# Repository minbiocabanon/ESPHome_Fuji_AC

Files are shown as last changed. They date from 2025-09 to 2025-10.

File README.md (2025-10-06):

# ESPHome_Fuji_AC

## Hardware

Totaly inspired by FOSV [Fuji Atom Interface](https://github.com/FOSV/Fuji-Atom-Interface). Great project but I bring these improvements :
- Easier composants to weld (size >= 0603, no QFN nor LGA)
- More 'professional' schematic design : schematic more , and organized, TVS added, decoupling capacitors and datasheet recommandations added.
- More 'professional' layout design : use power plan, 4 layers stackup, and state-of-art routing rules (EMC, DFx rules,...)
- Add minors improvments : 12V/5V leds, testpoints, reverse polarity protection on 12V.

Design tools
- Altium Designer 25.8

### What does it looks like ?

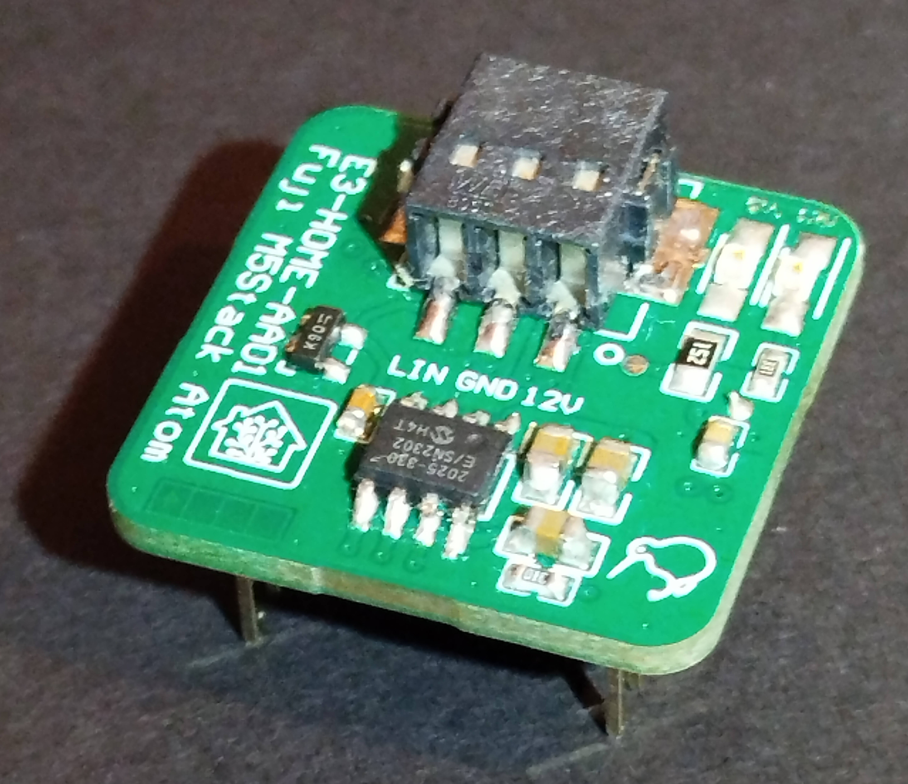
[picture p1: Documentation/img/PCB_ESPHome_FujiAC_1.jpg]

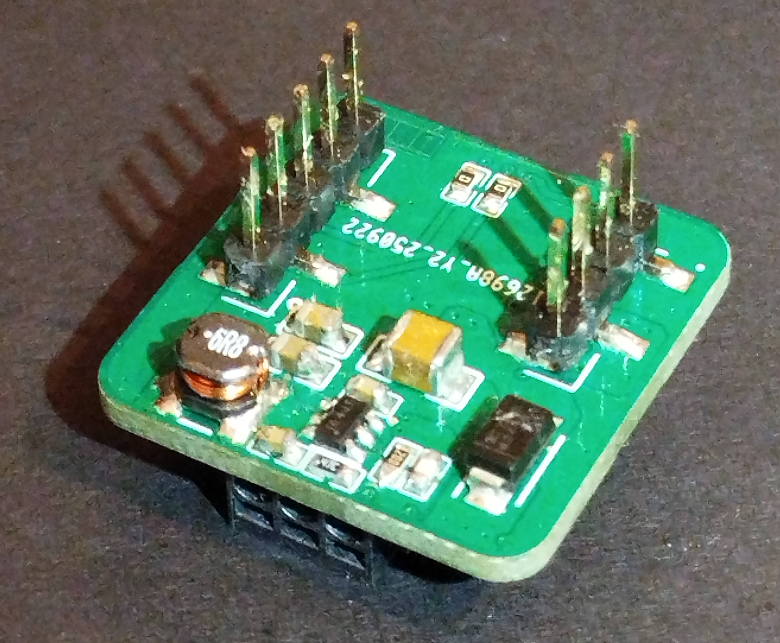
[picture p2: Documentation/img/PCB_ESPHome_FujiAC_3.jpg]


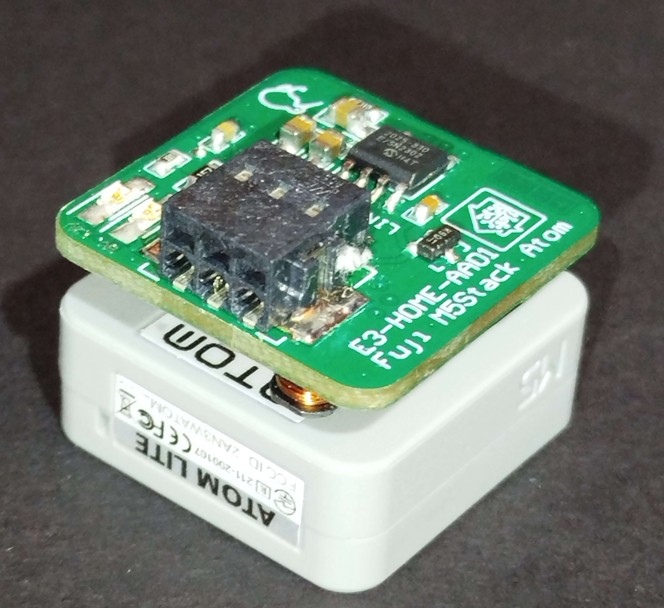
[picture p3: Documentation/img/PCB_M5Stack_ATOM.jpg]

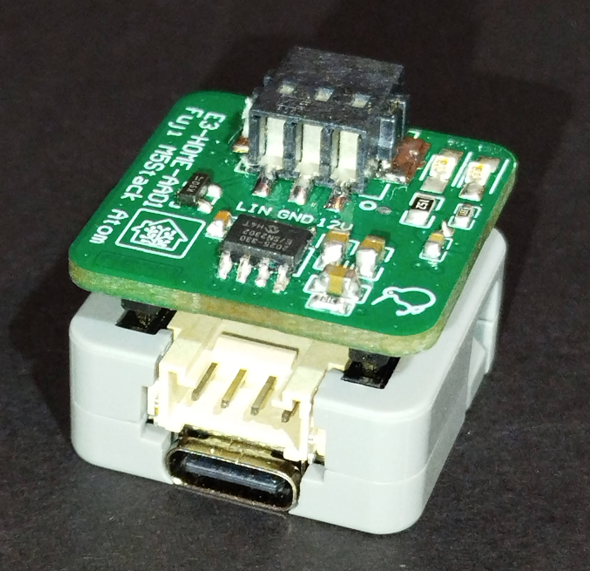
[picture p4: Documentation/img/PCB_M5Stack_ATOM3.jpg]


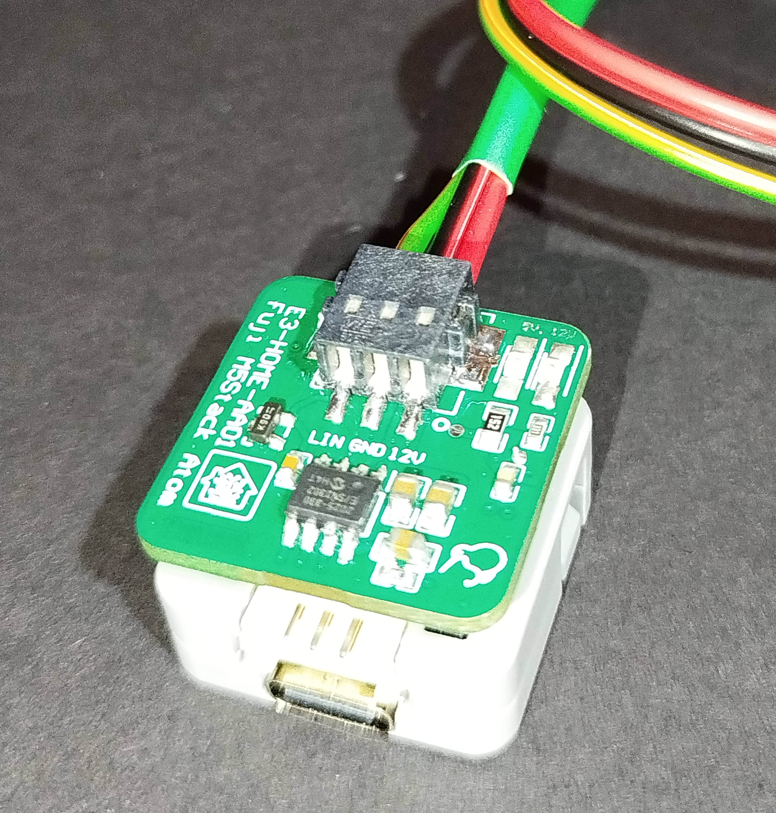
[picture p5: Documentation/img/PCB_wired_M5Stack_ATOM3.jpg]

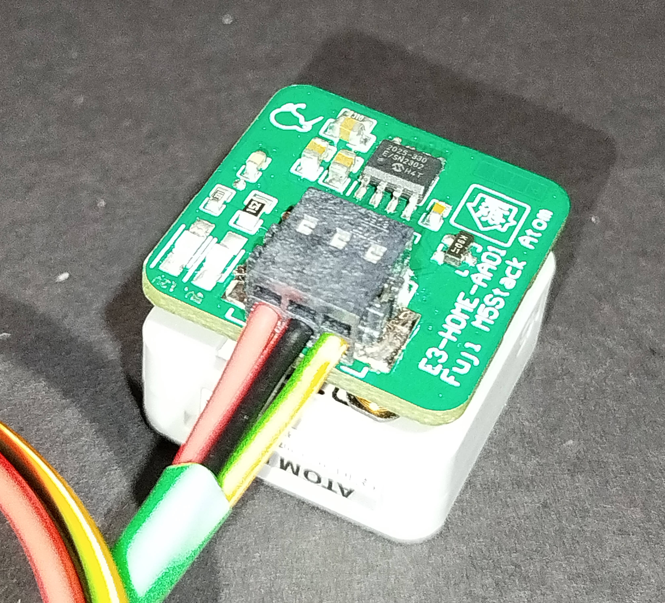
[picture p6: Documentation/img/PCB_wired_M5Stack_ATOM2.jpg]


## Software

This board can run Omniflux repo [esphome-fujitsu-halcyon](https://github.com/Omniflux/esphome-fujitsu-halcyon)

### ESPHome
This project runs under ESPHome 2025.7.
Not tested with newer version.

### YAML

```
substitutions:
  device_name: "fuji-controller"
  friendly_name: Halcyon Controller
  device_description: Atom Lite + FOSV
  esp_board: m5stack-atom

external_components:
  - source: github://Omniflux/esphome-tzsp
  - source: github://Omniflux/esphome-fujitsu-halcyon

packages:
  #wifi: !include common/wifi.yaml

esphome:
  name: ${device_name}
  friendly_name: ${friendly_name}
  comment: ${device_description}

esp32:
  board: ${esp_board}
  framework:
    type: esp-idf

#logger:
#  level: DEBUG

button:
  - platform: restart
    name: Restart
  - platform: safe_mode
    name: Restart (Safe Mode)

sensor:
- platform: uptime
  name: "Uptime"

uart:
  tx_pin: GPIO22  # Device dependent
  rx_pin: GPIO19  # Device dependent
  baud_rate: 500
  parity: EVEN

climate:
- platform: fujitsu-halcyon
  name: None  # Use device friendly_name

  # Fujitsu devices use 0 and 1, but 2-15 should also work. Must not skip addresses
  controller_address: 1  # 0=Primary, 1=Secondary
  #temperature_controller_address: 0  # Fujitsu controller address to read temperature from

  #temperature_sensor_id: my_temperature_sensor  # ESPHome sensor to read temperature from
  #humidity_sensor: my_humidity_sensor  # ESPHome sensor to read humidity from

  #ignore_lock: true  # Ignore child/part/feature lock set on unit or primary/central remote control

  # To capture communications for debugging / analysis
  # Use Wireshark with https://github.com/Omniflux/fujitsu-airstage-h-dissector
  #tzsp:
  #  ip: 192.168.1.20
  #  protocol: 255

# Enable logging
logger:

# Enable Home Assistant API
api:
  encryption:
    key: "xxx"

ota:
  - platform: esphome
    password: "xxx"

wifi:
  ssid: !secret wifi_ssid
  password: !secret wifi_password

  # Enable fallback hotspot (captive portal) in case wifi connection fails
  ap:
    ssid: "Test-Halcyon Fallback Hotspot"
    password: "xxx"

captive_portal:
```

### Screenshot of interface 
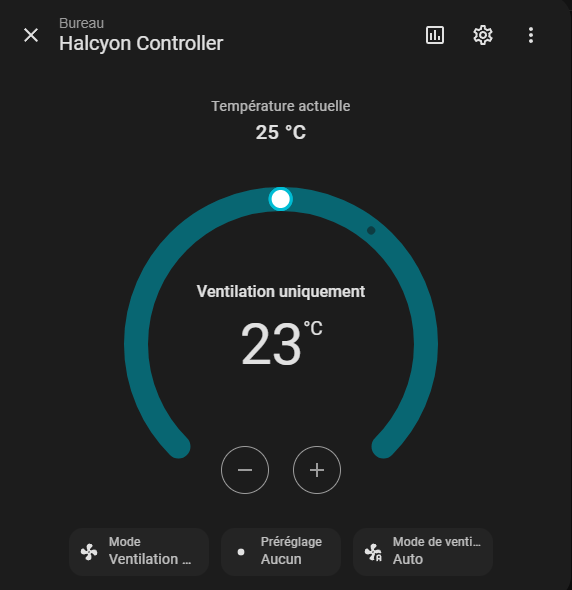
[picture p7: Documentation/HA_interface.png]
Screenshot of interface


## Related projects
- FOSV's [Fuji-Atom-Interface](https://github.com/FOSV/Fuji-Atom-Interface)
- Omniflux repo [esphome-fujitsu-halcyon](https://github.com/Omniflux/esphome-fujitsu-halcyon)
<!-- -->
- Aaron Zhang's [esphome-fujitsu](https://github.com/FujiHeatPump/esphome-fujitsu)
- Jaroslaw Przybylowicz's [fuji-iot](https://github.com/jaroslawprzybylowicz/fuji-iot)
- Raal Goff's [FujiHeatPump](https://github.com/unreality/FujiHeatPump)
- Raal Goff's [FujiHK](https://github.com/unreality/FujiHK)
<!-- -->
- Myles Eftos's [Reverse engineering](https://hackaday.io/project/19473-reverse-engineering-a-fujitsu-air-conditioner-unit)

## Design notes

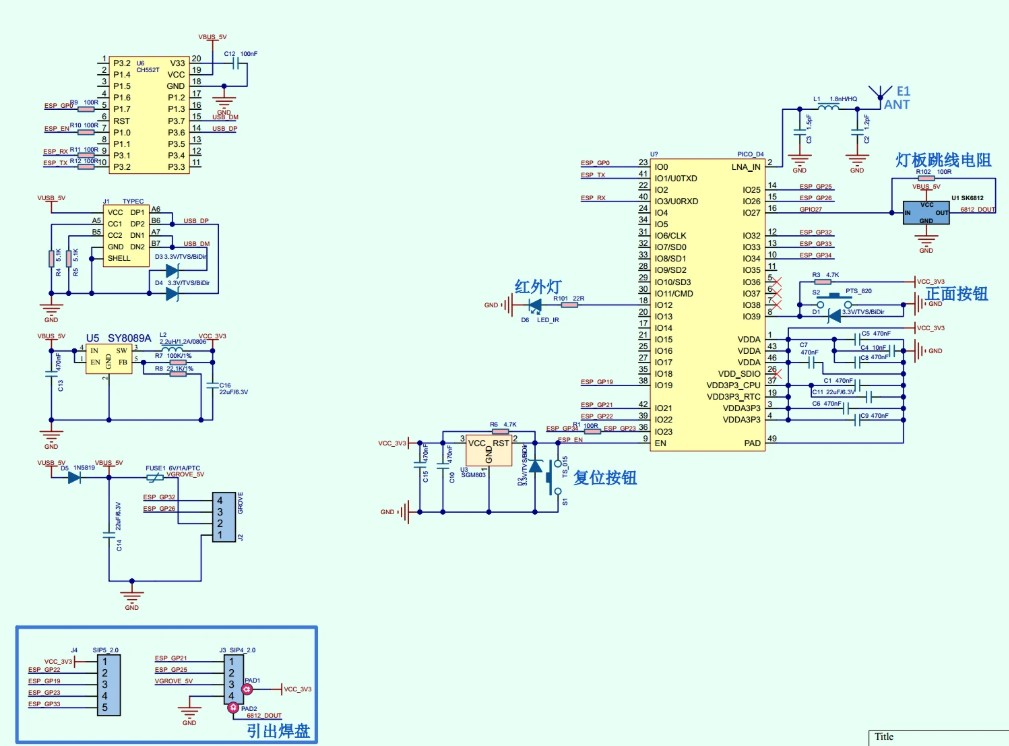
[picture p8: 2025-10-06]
Documentation/Atom_LITE_schematic.jpg

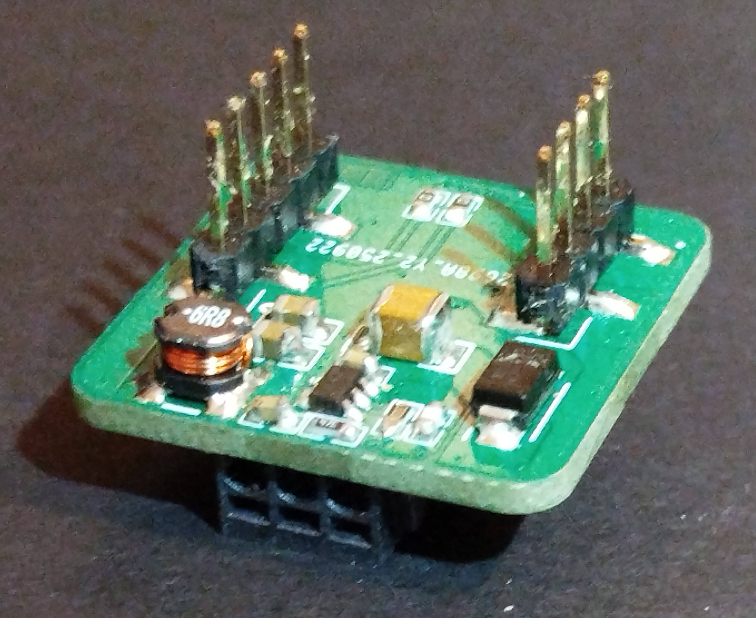
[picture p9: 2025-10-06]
Documentation/img/PCB_ESPHome_FujiAC_2.jpg

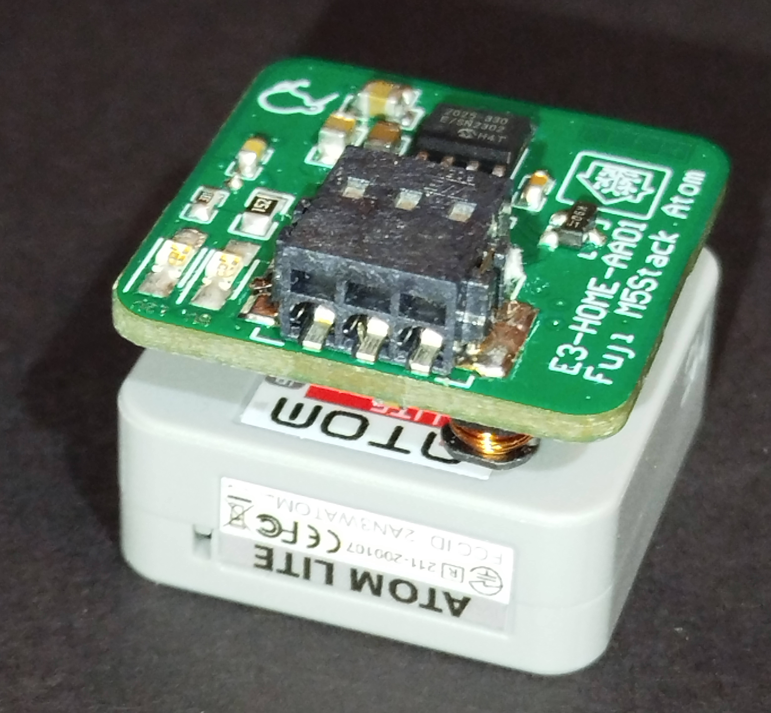
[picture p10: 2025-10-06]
Documentation/img/PCB_M5Stack_ATOM2.jpg

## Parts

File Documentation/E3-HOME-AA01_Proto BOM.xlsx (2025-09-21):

Designator | Comment | Manufacturer Part Number | Manufacturer | Description | Pins | Mounting Type | Layer | Quantity | Commande
J100 | 691805010303 | 691805010303 | Wurth Elektronik | WR-TBL Series 8050 - 3 pins 2.50 mm Screwless SMT | 8 | CMS | Bottom | 1 | Samples demandés à WE
U100 | AP63300WU-7 | AP63300WU-7 | Diodes Incorporated | Régulateurs de tension de commutation DCDC Conv HV Buck TSOT26 T&R 3K | 6 | CMS | Top | 1 | OI
D102, D103 | APT3216LZGCK | APT3216LZGCK | Kingbright | LED CMS Green 3.2x1.6mm | 2 | CMS | Bottom | 2 | Samples demandés à WE
D100 | B340A-13-F | B340A-13-F | Diodes | Diodes et redresseurs Schottky 40V 3A | 2 | CMS | Top | 1 | OI
C101 | 10uF | CAPA_CMS_10uF_50V_1206_10%_X7R |  | 10uF_50V_1206_10%_X7R | 2 | CMS | Top | 1 | OI
C104, C105, C106, C107, C108 | 22uF | CAPA_CMS_22uF_16V_0805_10%_X5R |  | 22uF_16V_0805_10%_X5R | 2 | CMS | Top, Bottom | 5 | OI
C103 | 47pF | CAPA_CMS_47pF_50V_0603_5%_X7R |  | 47pF_50V_0603_5%_X7R | 2 | CMS | Top | 1 | OI
C100, C102, C109 | 100nF | CAPA_CMS_100nF_50V_0603_5%_X7R |  | 100nF_50V_0603_5%_X7R | 2 | CMS | Top, Bottom | 3 | OI
C110 | 220pF | CAPA_CMS_220pF_50V_0603_10%_X7R |  | 220pF_50V_0603_10%_X7R | 2 | CMS | Bottom | 1 | OI
PCB1 | E7-HOME-AA01 | E7-HOME-AA01 |  | PCB reference | 0 | NONE | None | 1
~~Stencil1~~ | ~~E9-HOME-AA01~~ | ~~E9-HOME-AA01~~ |  | ~~PCB stencil~~ | ~~0~~ | ~~NONE~~ | ~~None~~ | ~~1~~
U101 | MCP2025-330E-SN | MCP2025-330E/SN | Microchip | LIN Transceiver with Voltage Regulator SOIC 3.3V | 8 | CMS | Bottom | 1
D101 | MMBZ27VAL-7-F | MMBZ27VAL-7-F |  | Suppresseurs ESD / diodes TVS 27V 225mW | 3 | CMS | Bottom | 1 | OI
R104, R106 | 0 | RES_CMS_0_1/10W_0603_1% |  | 0_1/10W_0603_1% | 2 | CMS | Top | 2 | OI
R100 | 1K5 | RES_CMS_1K5_1/8W_0805_0.1% |  | 1K5_1/8W_0805_0.1% | 2 | CMS | Bottom | 1 | OI
R103, R105 | 30K1 | RES_CMS_30K1_1/10W_0603_1% |  | 30K1_1/10W_0603_1% | 2 | CMS | Top, Bottom | 2 | OI
R102 | 158K | RES_CMS_158K_1/16W_0603_1% |  | 158K_1/16W_0603_1% | 2 | CMS | Top | 1 | OI
R101 | 330 | RES_CMS_330_1/10W_0603_5% |  | 330_1/10W_0603_5% | 2 | CMS | Bottom | 1 | OI
L100 | SRN5040TA-6R8M | SRN5040TA-6R8M | Bourns | Inductance fixes 6.8uH 2.5A | 2 | CMS | Top | 1 | Samples demandés à WE
J101 | TSM-104-01-L-SV-P-TR | TSM-104-01-L-SV-P-TR | Samtec | Header male SMD 1x4 | 4 | CMS | Top | 1 | Samples demandés à WE
J102 | TSM-105-01-F-SV | TSM-105-01-F-SV | SAMTEC | Header male SMD 1x5 | 5 | CMS | Top | 1 | Samples demandés à WE

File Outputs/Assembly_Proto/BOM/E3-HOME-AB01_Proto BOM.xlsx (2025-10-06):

Manufacturer Part Number | Manufacturer | Comment | Description | Designator | Pins | Mounting Type | Layer | Quantity
691805010303 | Wurth Elektronik | 691805010303 | WR-TBL Series 8050 - 3 pins 2.50 mm Screwless SMT | J100 | 8 | CMS | Bottom | 1
AP63300WU-7 | Diodes Incorporated | AP63300WU-7 | Régulateurs de tension de commutation DCDC Conv HV Buck TSOT26 T&R 3K | U100 | 6 | CMS | Top | 1
APT3216LZGCK | Kingbright | APT3216LZGCK | LED CMS Green 3.2x1.6mm | D102, D103 | 2 | CMS | Bottom | 2
B340A-13-F | Diodes | B340A-13-F | Diodes et redresseurs Schottky 40V 3A | D100 | 2 | CMS | Top | 1
CAPA_CMS_10uF_50V_1206_10%_X7R |  | 10uF | 10uF_50V_1206_10%_X7R | C101 | 2 | CMS | Top | 1
CAPA_CMS_22uF_16V_0805_10%_X5R |  | 22uF | 22uF_16V_0805_10%_X5R | C104, C105, C106, C107, C108 | 2 | CMS | Top, Bottom | 5
CAPA_CMS_47pF_50V_0603_5%_X7R |  | 47pF | 47pF_50V_0603_5%_X7R | C103 | 2 | CMS | Top | 1
CAPA_CMS_100nF_50V_0603_5%_X7R |  | 100nF | 100nF_50V_0603_5%_X7R | C100, C102, C109 | 2 | CMS | Top, Bottom | 3
CAPA_CMS_220pF_50V_0603_10%_X7R |  | 220pF | 220pF_50V_0603_10%_X7R | C110 | 2 | CMS | Bottom | 1
E7-HOME-AB01 |  | E7-HOME-AB01 | PCB reference | PCB1 | 0 | NONE | None | 1
E9-HOME-AB01 |  | E9-HOME-AB01 | PCB stencil | Stencil1 | 0 | NONE | None | 1
MCP2025-330E/SN | Microchip | MCP2025-330E-SN | LIN Transceiver with Voltage Regulator SOIC 3.3V | U101 | 8 | CMS | Bottom | 1
MMBZ27VAL-7-F |  | MMBZ27VAL-7-F | Suppresseurs ESD / diodes TVS 27V 225mW | D101 | 3 | CMS | Bottom | 1
RES_CMS_0_1/10W_0603_1% |  | 0 | 0_1/10W_0603_1% | R104, R106 | 2 | CMS | Top | 2
RES_CMS_1K_1/10W_0603_1% |  | 1K | 1K_1/10W_0603_1% | R101 | 2 | CMS | Bottom | 1
RES_CMS_3K_1/8W_0805_1% |  | 3K | 3K_1/8W_0805_1% | R100 | 2 | CMS | Bottom | 1
RES_CMS_30K1_1/10W_0603_1% |  | 30K1 | 30K1_1/10W_0603_1% | R103, R105 | 2 | CMS | Top, Bottom | 2
RES_CMS_158K_1/16W_0603_1% |  | 158K | 158K_1/16W_0603_1% | R102 | 2 | CMS | Top | 1
SRN5040TA-6R8M | Bourns | SRN5040TA-6R8M | Inductance fixes 6.8uH 2.5A | L100 | 2 | CMS | Top | 1
TSM-104-01-L-SV-P-TR | Samtec | TSM-104-01-L-SV-P-TR | Header male SMD 1x4 | J101 | 4 | CMS | Top | 1
TSM-105-01-F-SV | SAMTEC | TSM-105-01-F-SV | Header male SMD 1x5 | J102 | 5 | CMS | Top | 1

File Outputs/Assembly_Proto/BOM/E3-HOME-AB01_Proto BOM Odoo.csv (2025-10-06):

Manufacturer Part Number | Quantity | Layer
691805010303 | 1 | Bottom
AP63300WU-7 | 1 | Top
APT3216LZGCK | 2 | Bottom
B340A-13-F | 1 | Top
CAPA_CMS_10uF_50V_1206_10%_X7R | 1 | Top
CAPA_CMS_22uF_16V_0805_10%_X5R | 5 | Top, Bottom
CAPA_CMS_47pF_50V_0603_5%_X7R | 1 | Top
CAPA_CMS_100nF_50V_0603_5%_X7R | 3 | Top, Bottom
CAPA_CMS_220pF_50V_0603_10%_X7R | 1 | Bottom
E7-HOME-AB01 | 1 | None
E9-HOME-AB01 | 1 | None
MCP2025-330E/SN | 1 | Bottom
MMBZ27VAL-7-F | 1 | Bottom
RES_CMS_0_1/10W_0603_1% | 2 | Top
RES_CMS_1K_1/10W_0603_1% | 1 | Bottom
RES_CMS_3K_1/8W_0805_1% | 1 | Bottom
RES_CMS_30K1_1/10W_0603_1% | 2 | Top, Bottom
RES_CMS_158K_1/16W_0603_1% | 1 | Top
SRN5040TA-6R8M | 1 | Top
TSM-104-01-L-SV-P-TR | 1 | Top
TSM-105-01-F-SV | 1 | Top

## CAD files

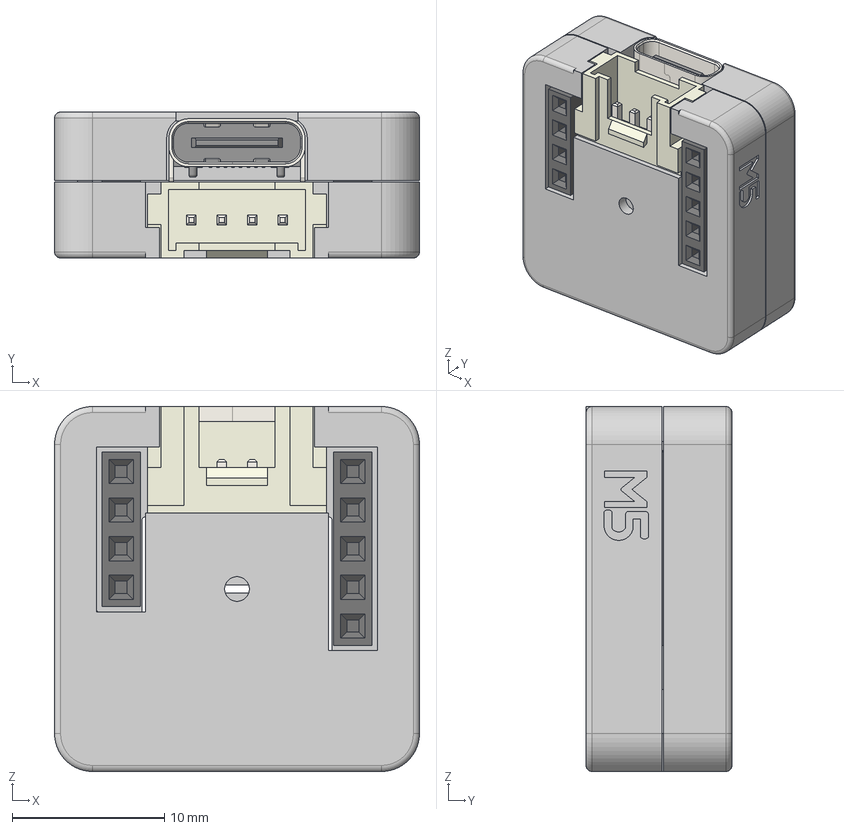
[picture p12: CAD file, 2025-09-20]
Documentation/M5 ATOM Lite.step
24.0 x 9.60 x 24.0 mm
Grove socket
pinsocket_5 v2
pinsocket_4 v3
ConPins
PcbPins
Mold
Frame

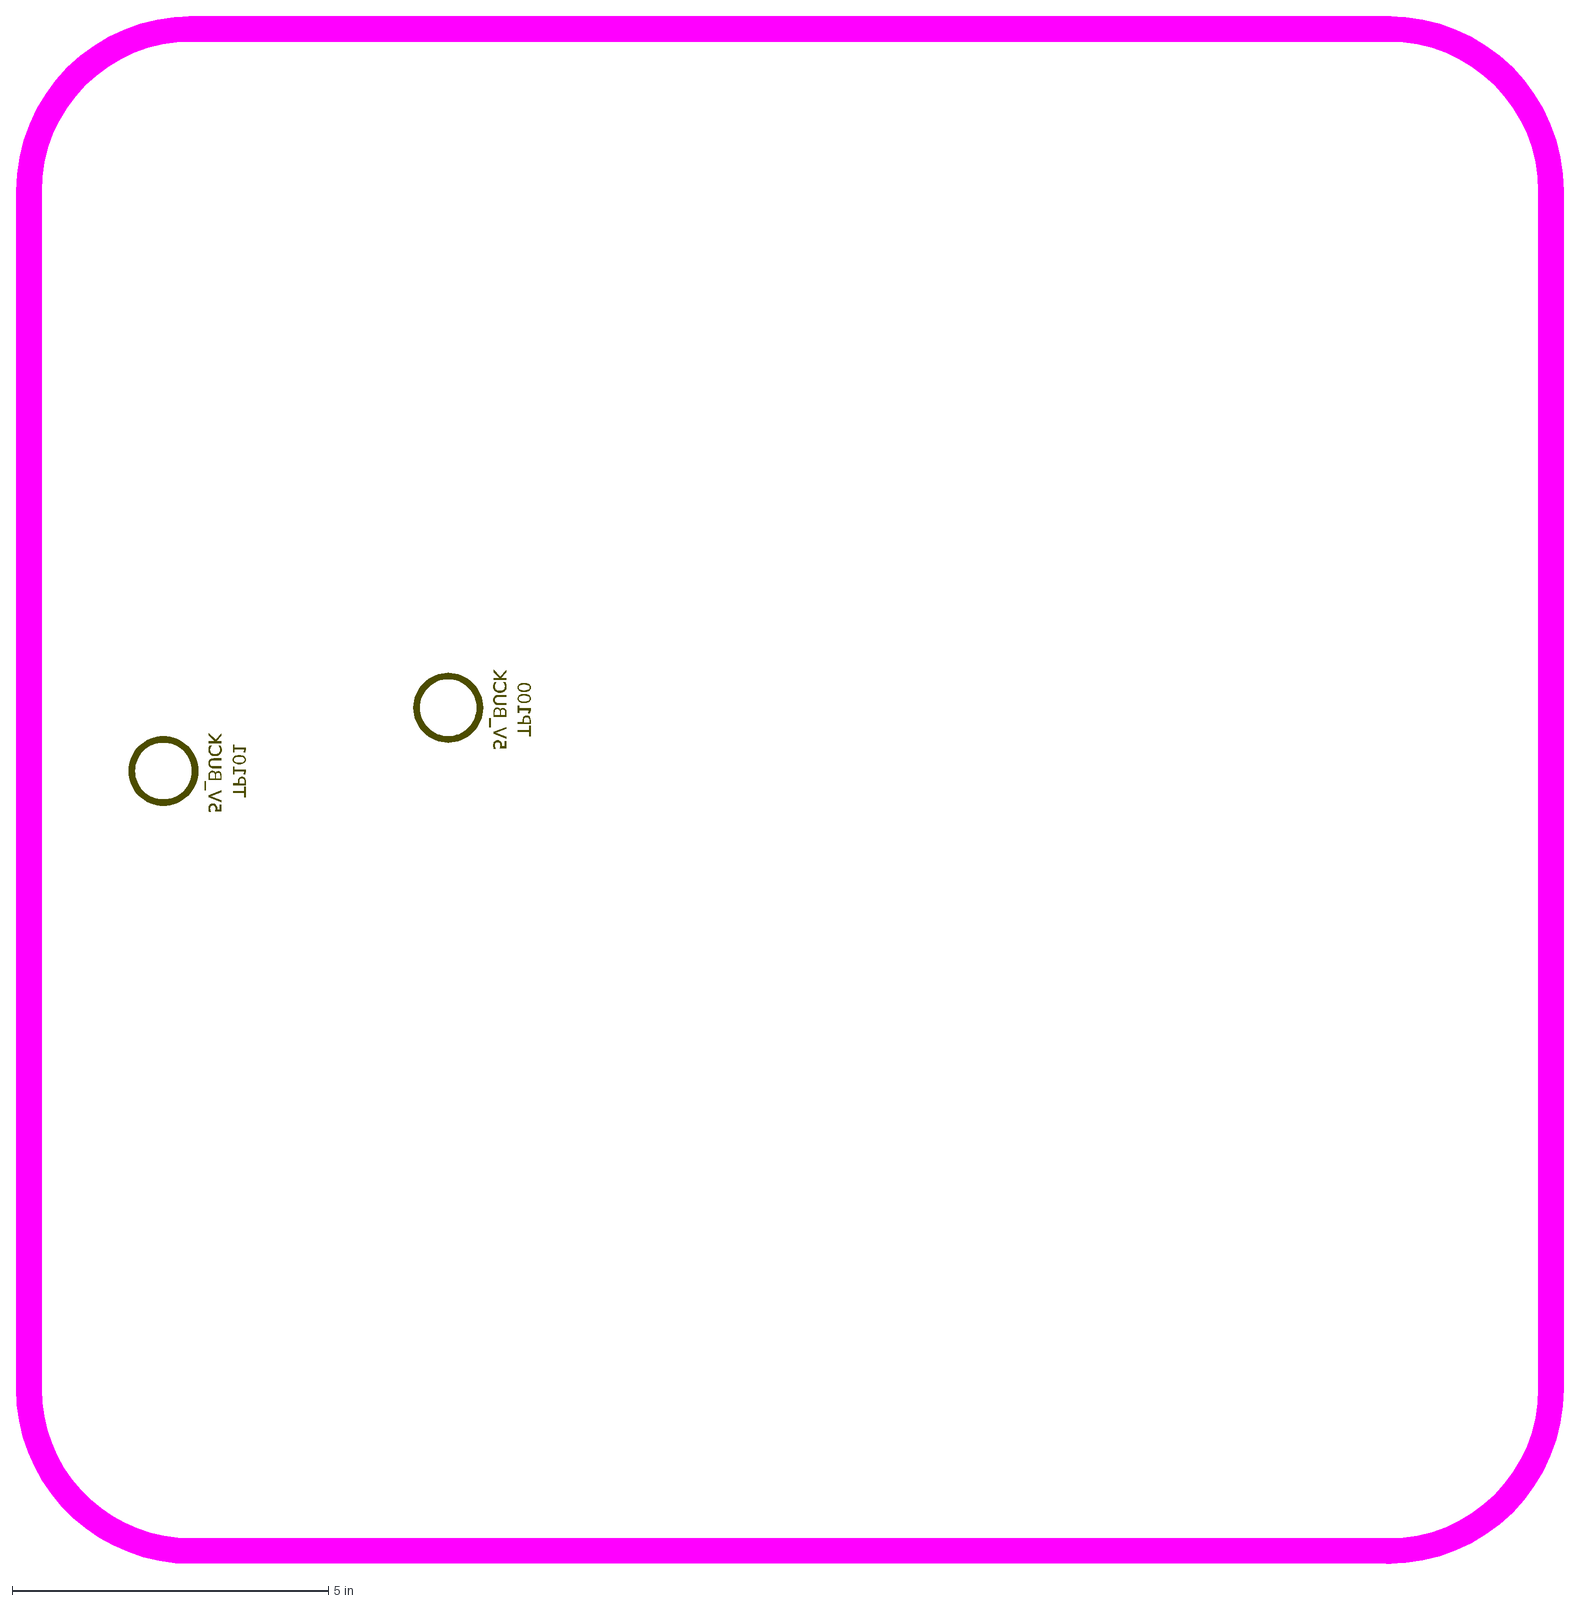
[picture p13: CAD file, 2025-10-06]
Outputs/Mechanical_Proto/E3-HOME-AB01_Proto DXF.DXF
5V_BUCK
TP101
TP100

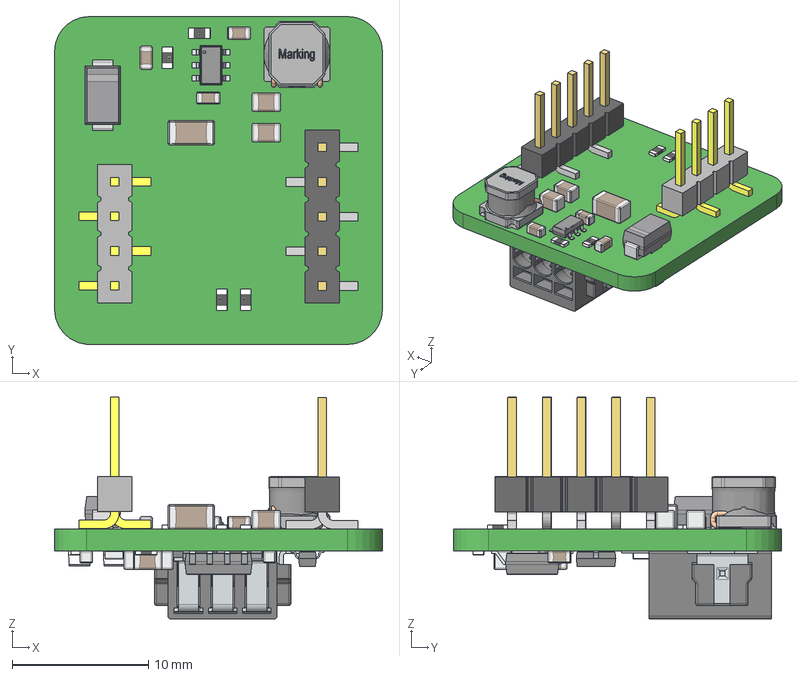
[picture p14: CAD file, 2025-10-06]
Outputs/Mechanical_Proto/E3-HOME-AB01_Proto STEP.step
24.0 x 24.0 x 16.3 mm
TSM-105-01-SV_body
T-1S6-16-F(-01-5-SV)
T-1S6-16-F(-01-5-SV)2
MMBZ27VAL-7-F
PinsArrayLR x 2
SW3dPS-0603 SMD Resistor x 6
T-1S6-16(-01-4-SV)
TSM-104-01-SV_body
6918050103xx_Solder tab x 2
6918050103xx_Pin2 x 3
6918050103xx_Pin1 x 3
User Library-5977703607F x 2
User Library-DO-214AC SMA

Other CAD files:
Outputs/Mechanical_Proto/E3-HOME-AB01_Proto PARASOLID.x_t

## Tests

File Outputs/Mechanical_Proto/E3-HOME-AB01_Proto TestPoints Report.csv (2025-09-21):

Net | Name | X Coord | Y Coord | Side | Hole Size | Type
5V | TP101-1 | 2.1mm | 12.3mm | Bottom | 0mm | Surface mount
12V_FP | TP100-1 | 6.6mm | 13.3mm | Bottom | 0mm | Surface mount

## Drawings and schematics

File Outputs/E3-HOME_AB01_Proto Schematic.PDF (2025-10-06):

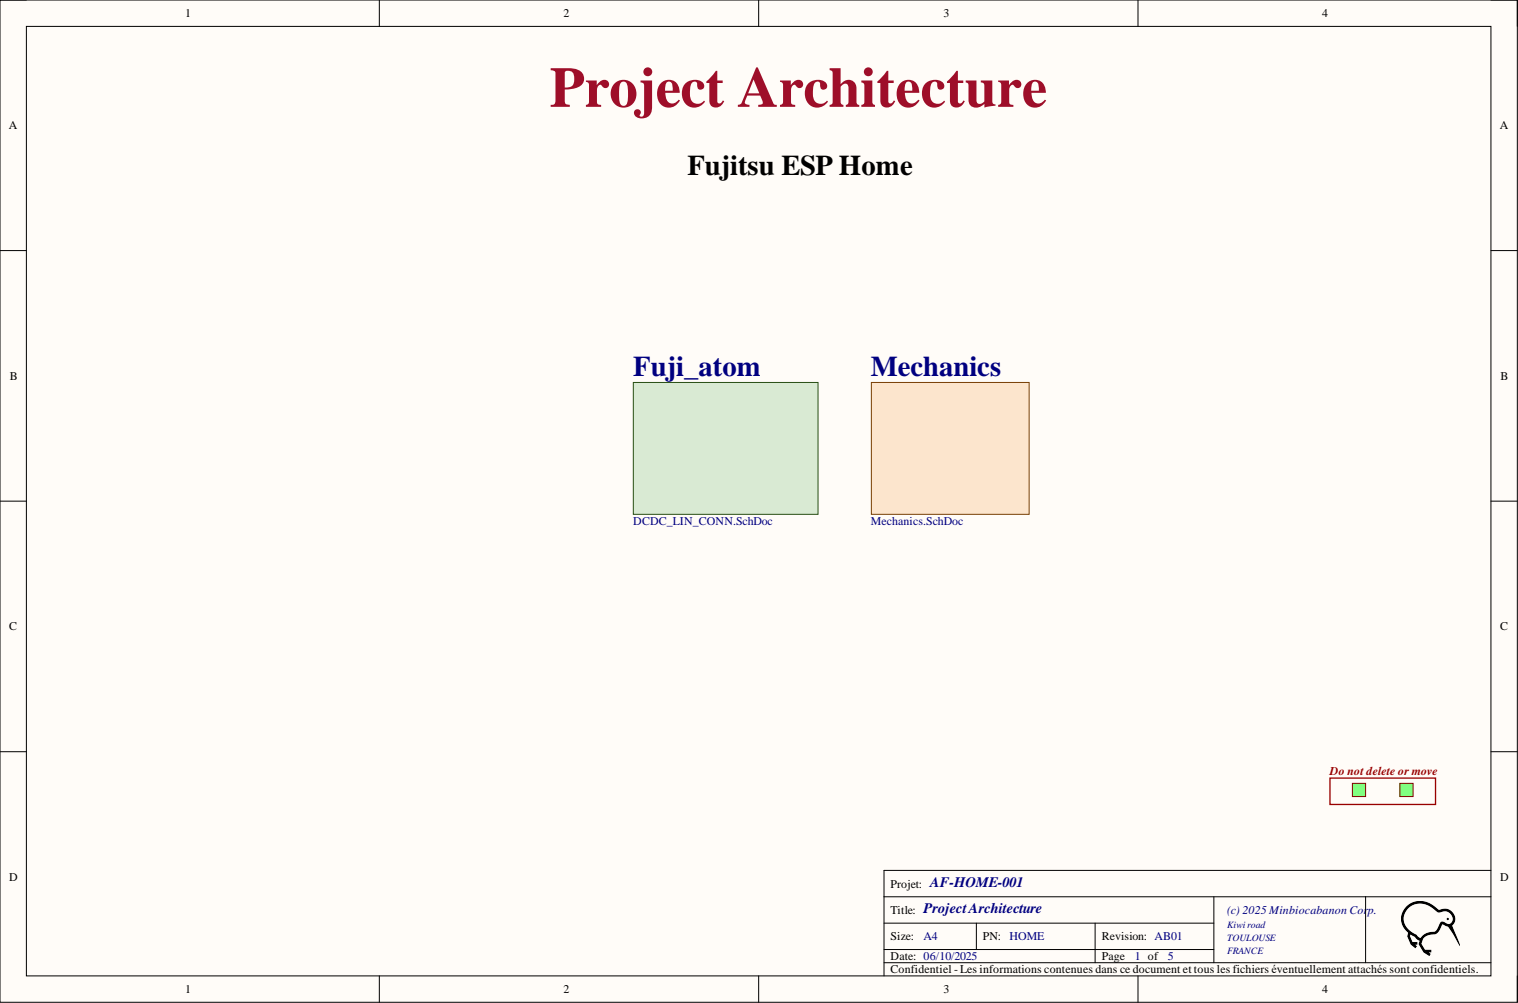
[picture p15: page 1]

Do not delete or move

Date:
Confidentiel - Les informations contenues dans ce document et tous les fichiers éventuellement attachés sont confidentiels.

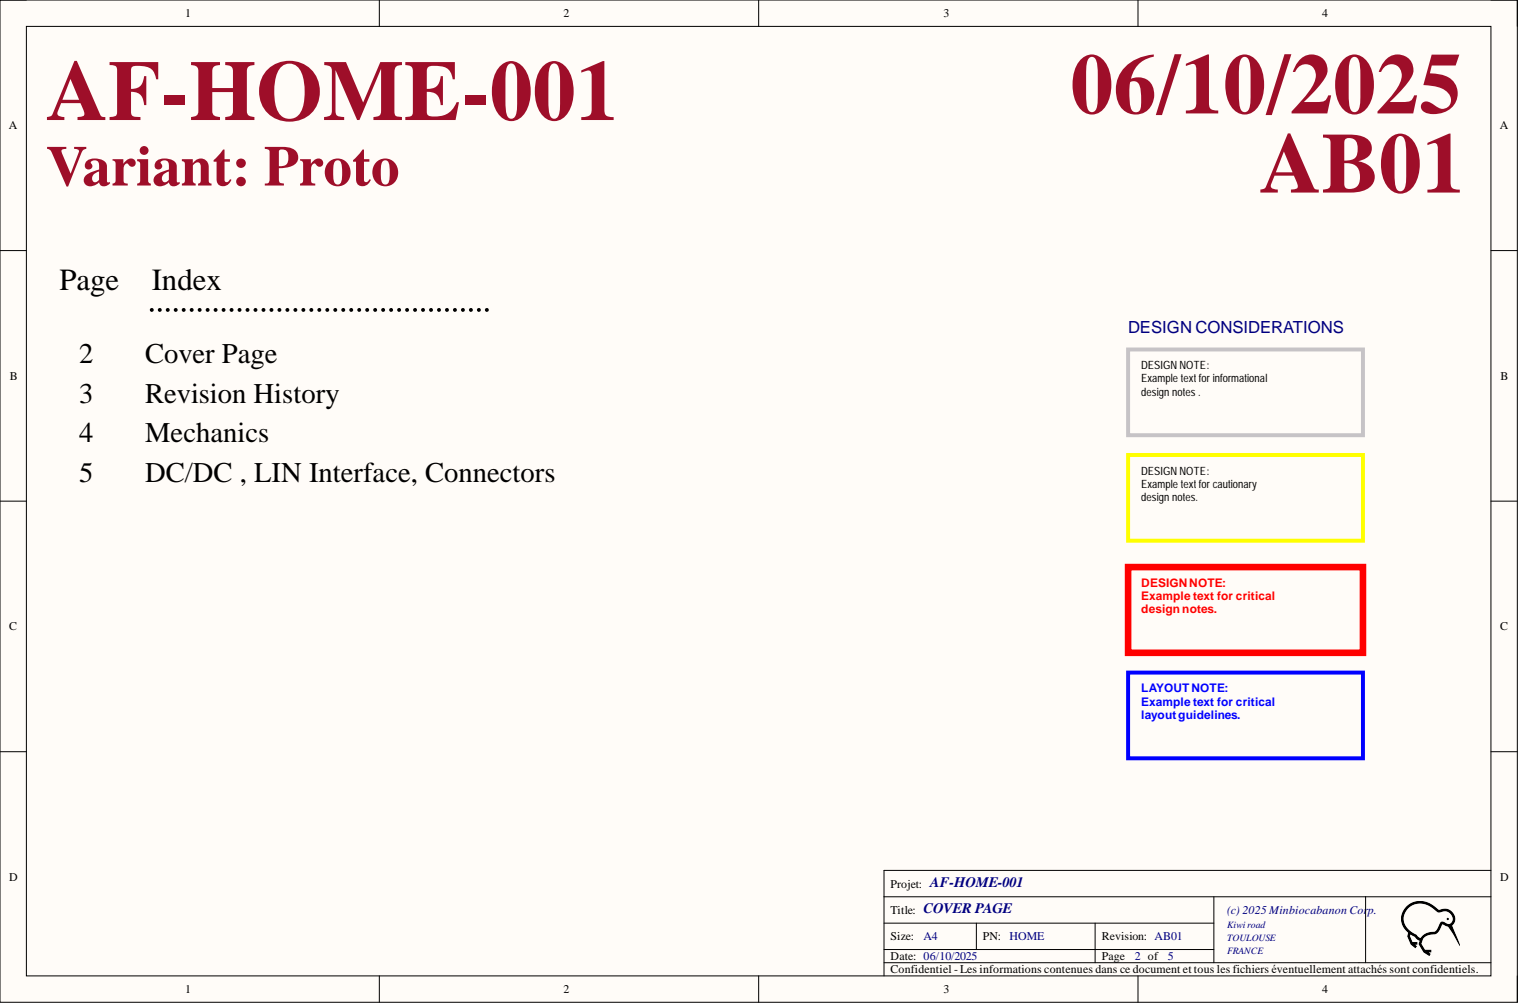
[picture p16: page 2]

DESIGN NOTE:
Example text for informational
design notes .

Example text for cautionary
design notes.

Example text for critical

LAYOUT NOTE:
layout guidelines.

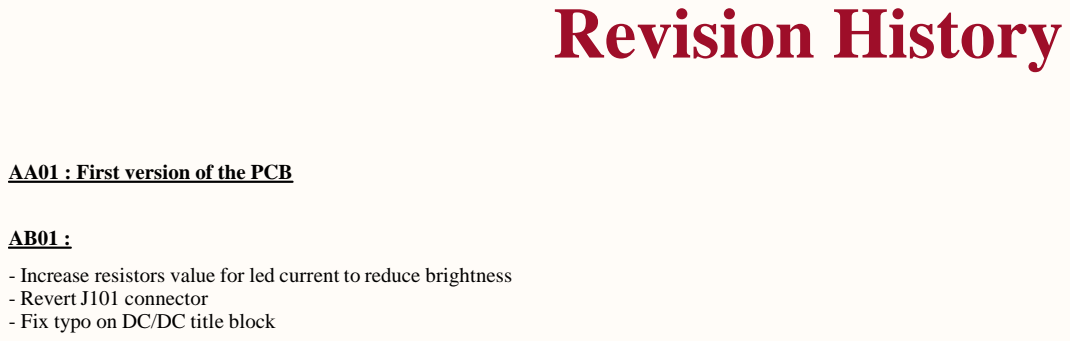
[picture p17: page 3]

AA01 : First version of the PCB

- Increase resistors value for led current to reduce brightness
- Revert J101 connector
- Fix typo on DC/DC title block

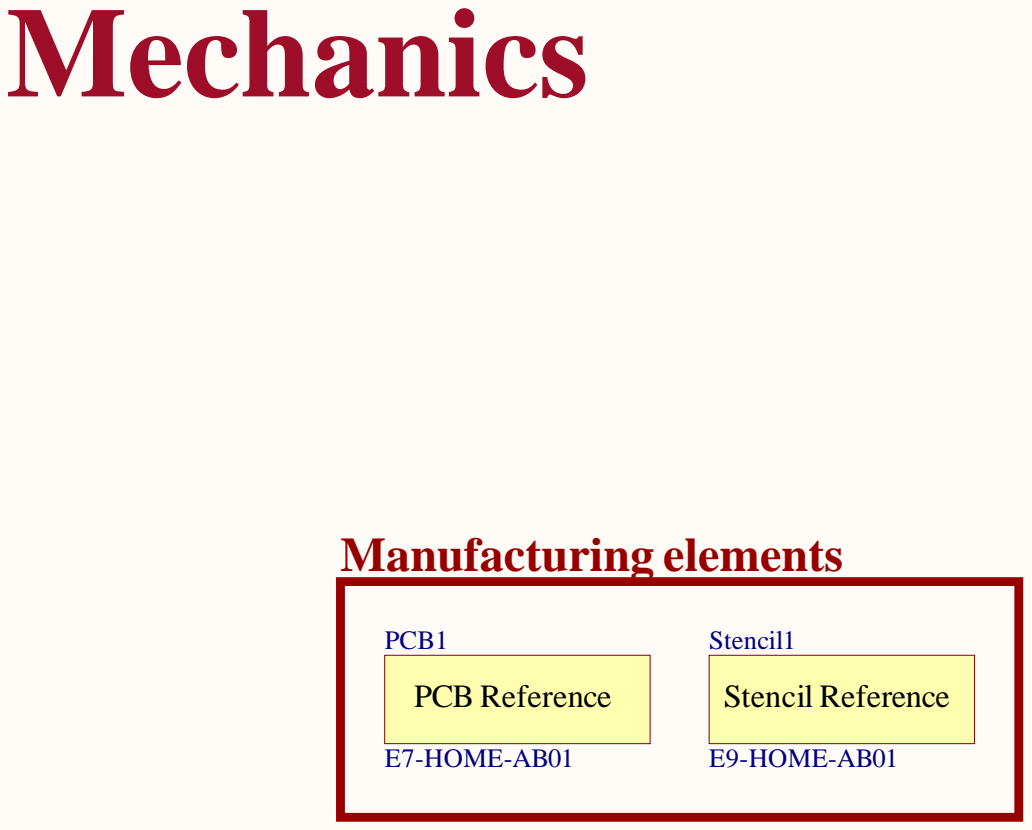
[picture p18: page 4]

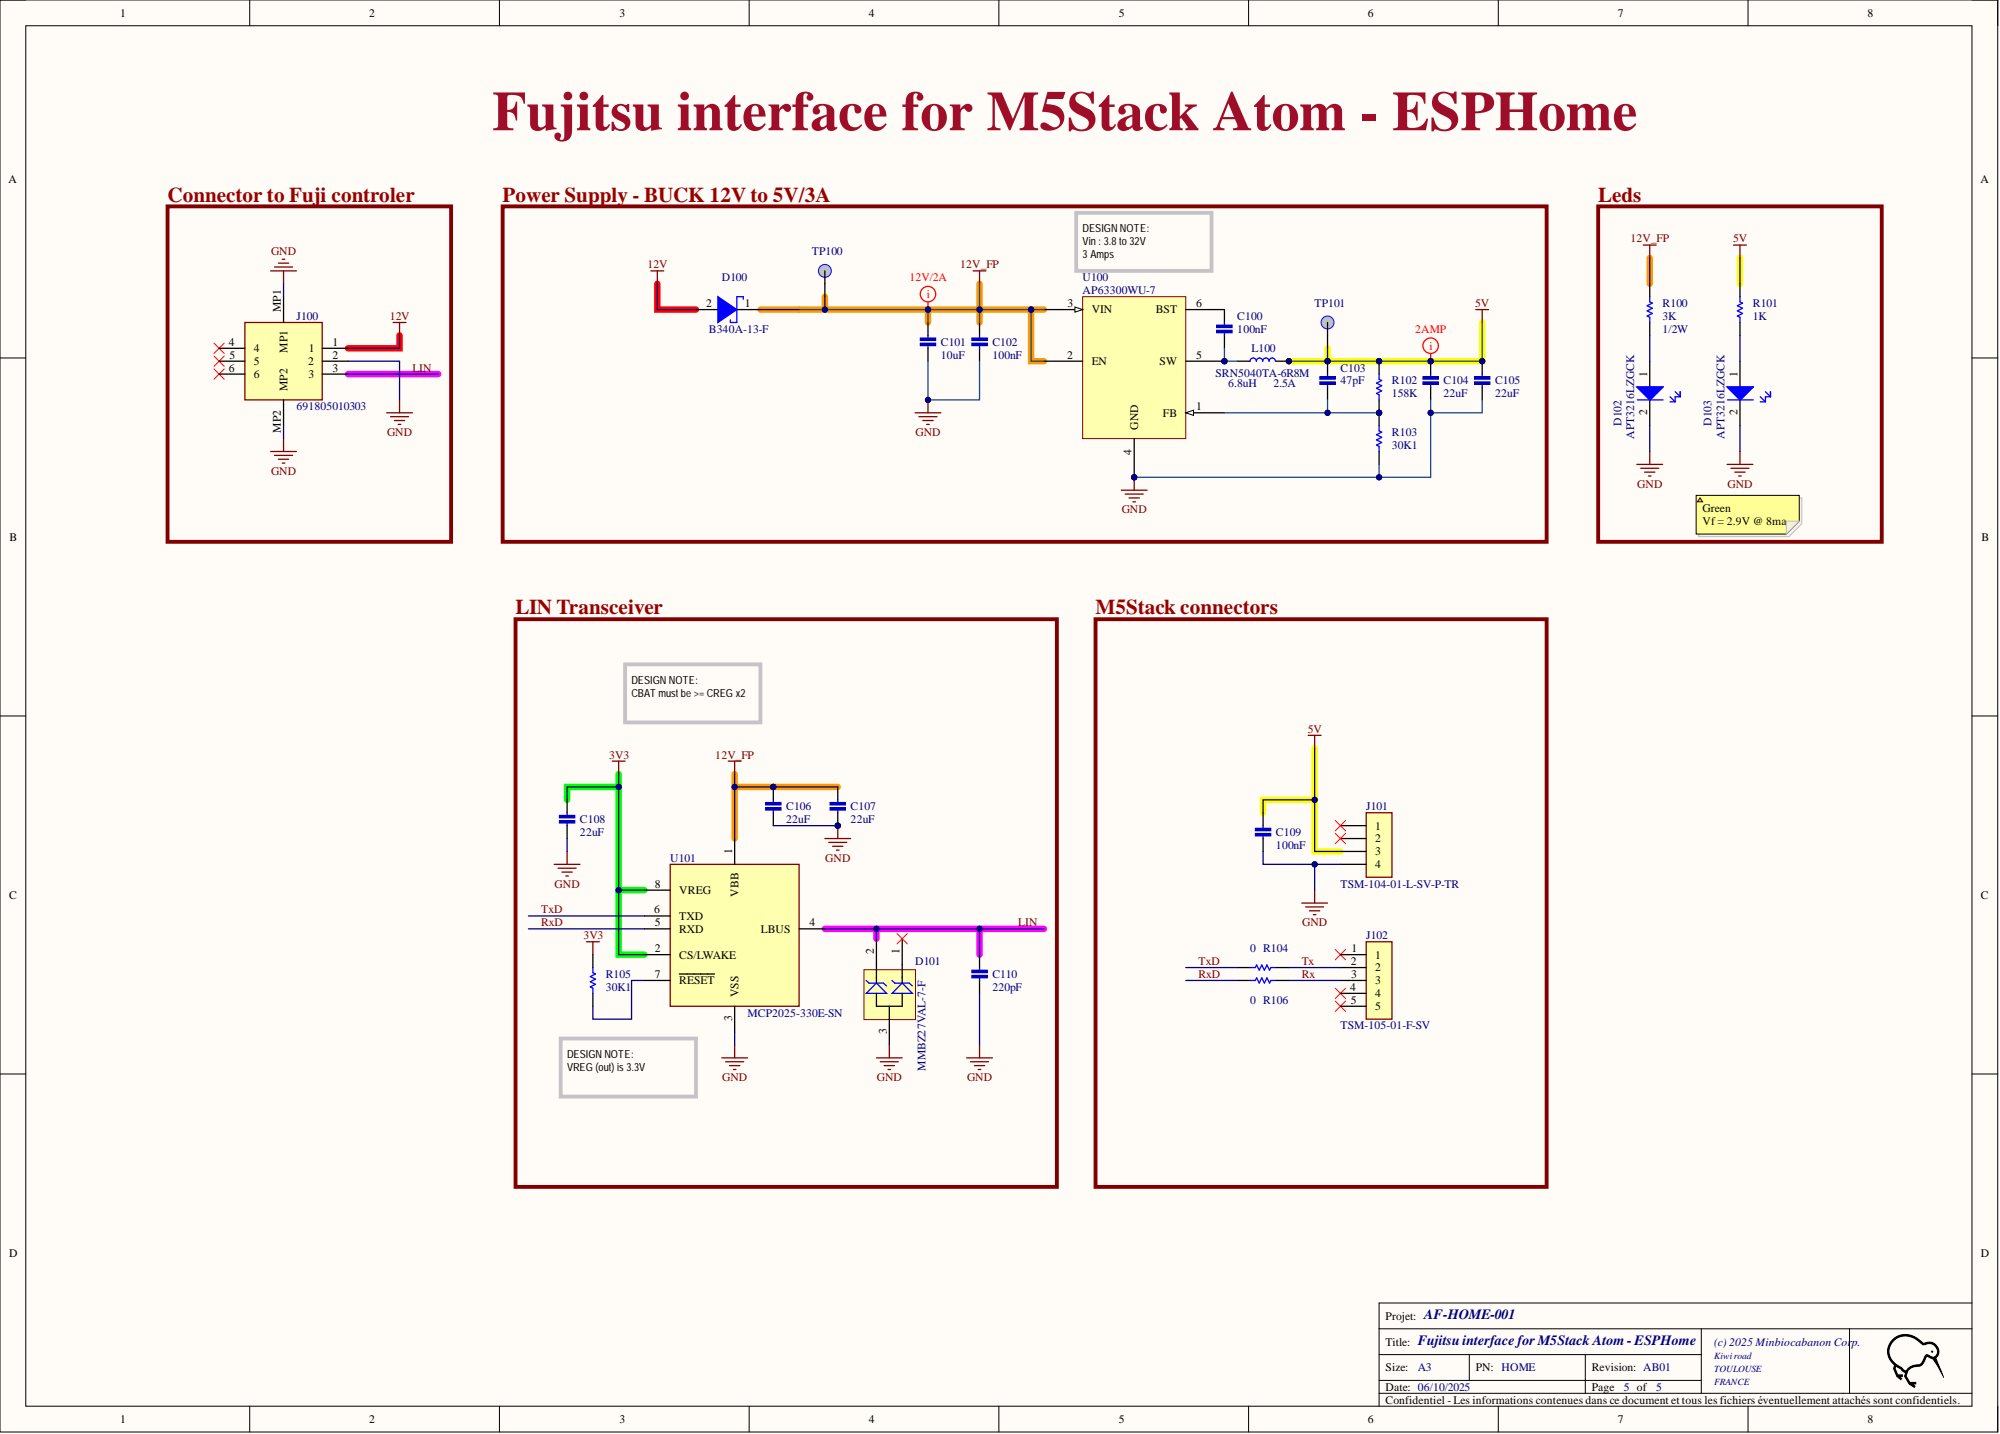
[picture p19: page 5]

Fujitsu interface for M5Stack Atom - ESPHome

Connector to Fuji controler

Power Supply - BUCK 12V to 5V/3A

DESIGN NOTE:
CBAT must be >= CREG x2

TSM-104-01-L-SV-P-TR VBB 1

Projet:
Title:

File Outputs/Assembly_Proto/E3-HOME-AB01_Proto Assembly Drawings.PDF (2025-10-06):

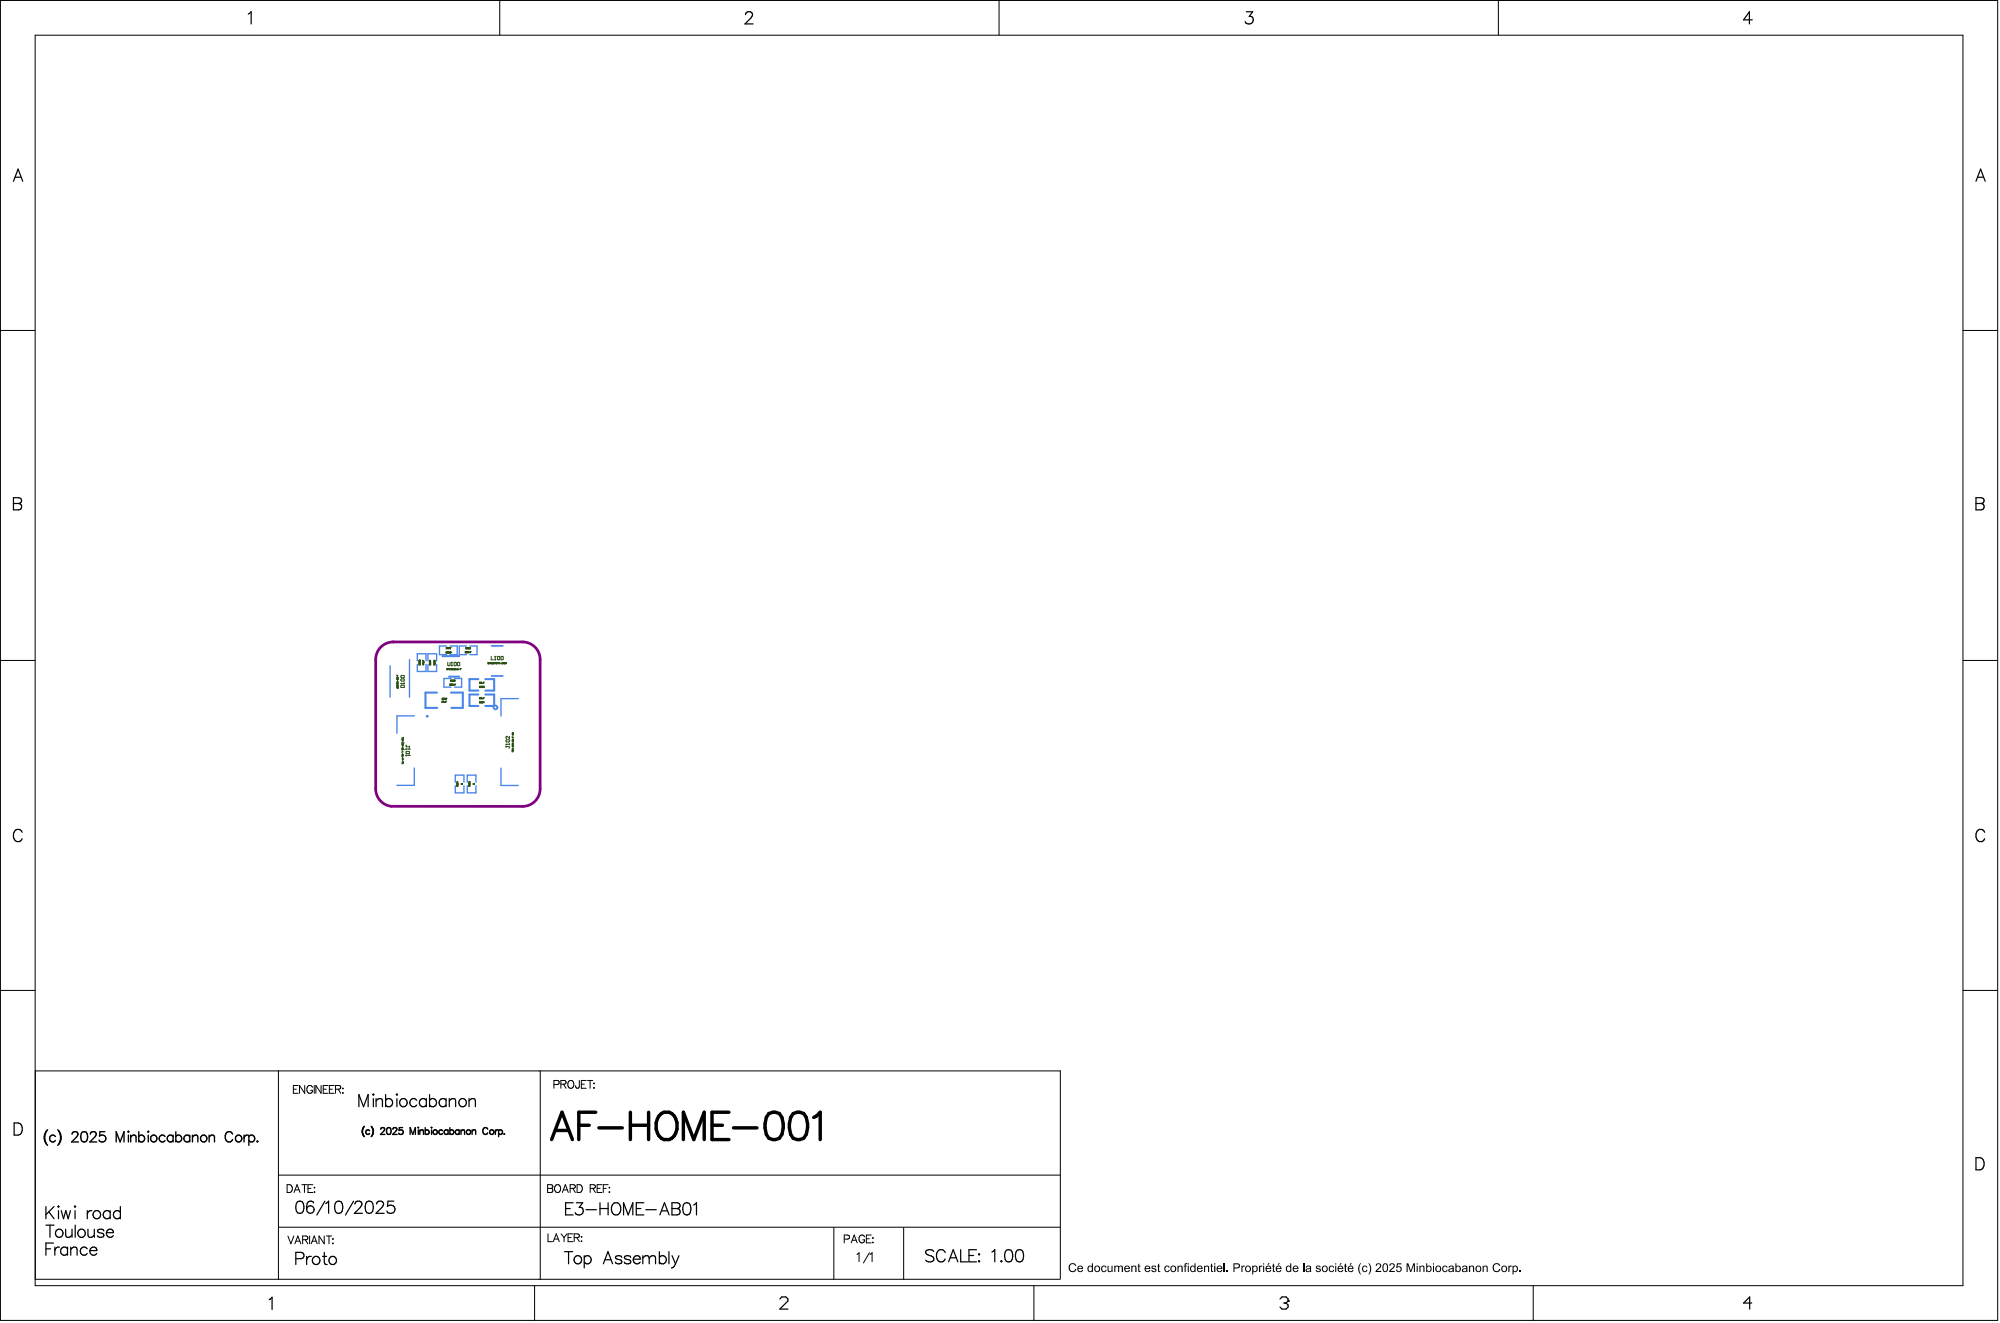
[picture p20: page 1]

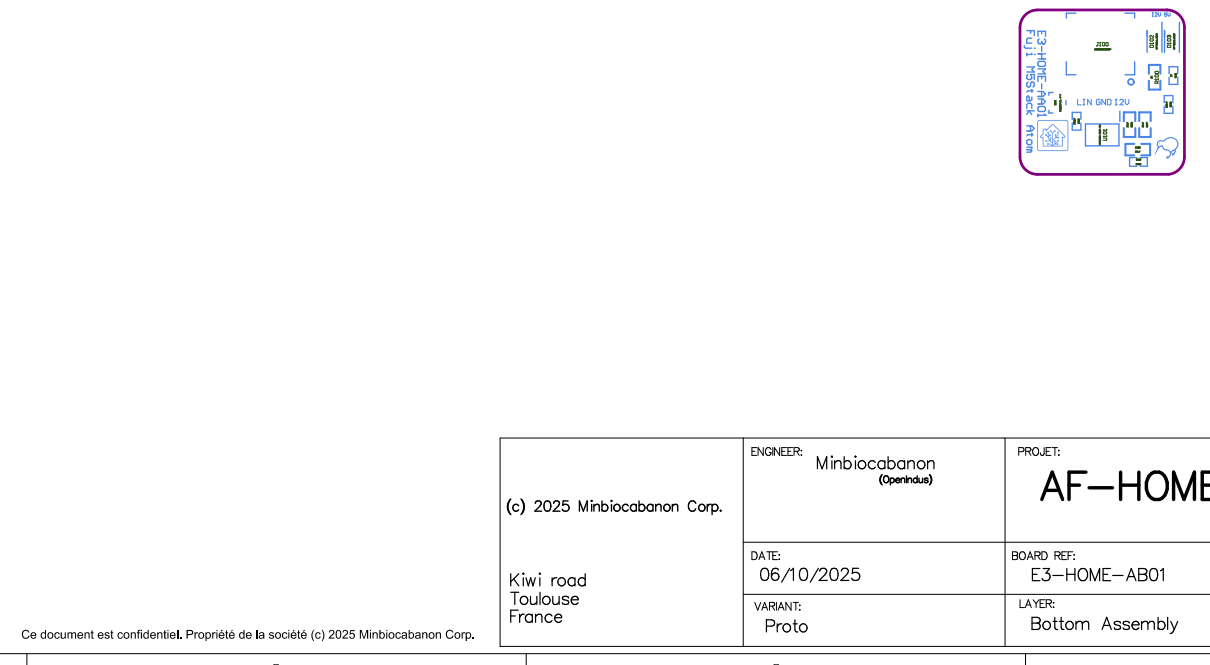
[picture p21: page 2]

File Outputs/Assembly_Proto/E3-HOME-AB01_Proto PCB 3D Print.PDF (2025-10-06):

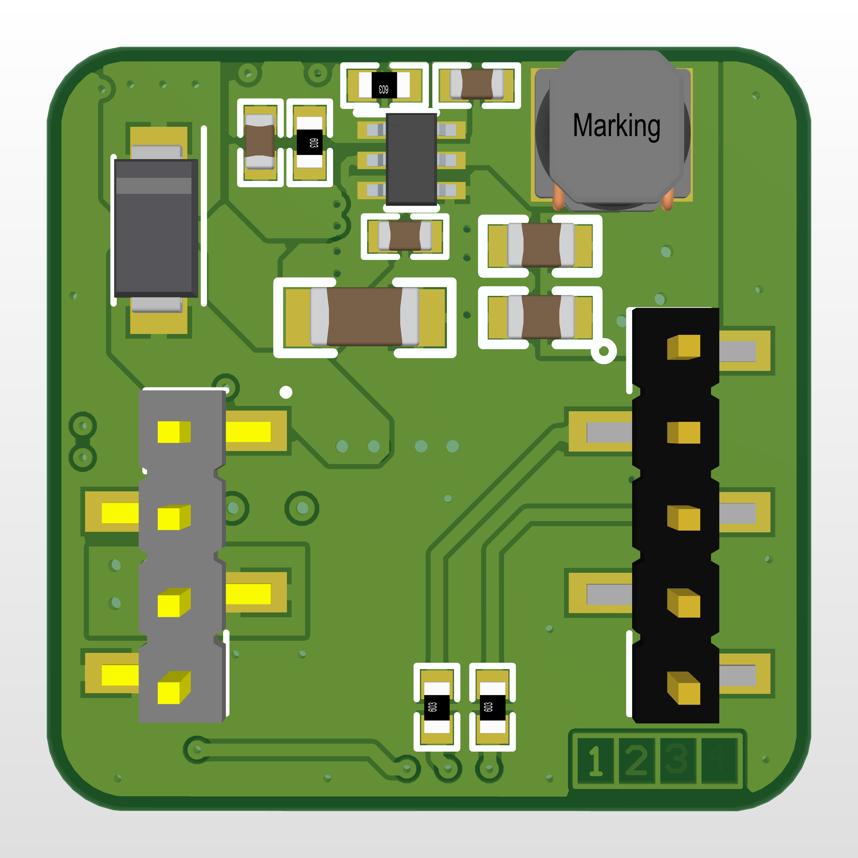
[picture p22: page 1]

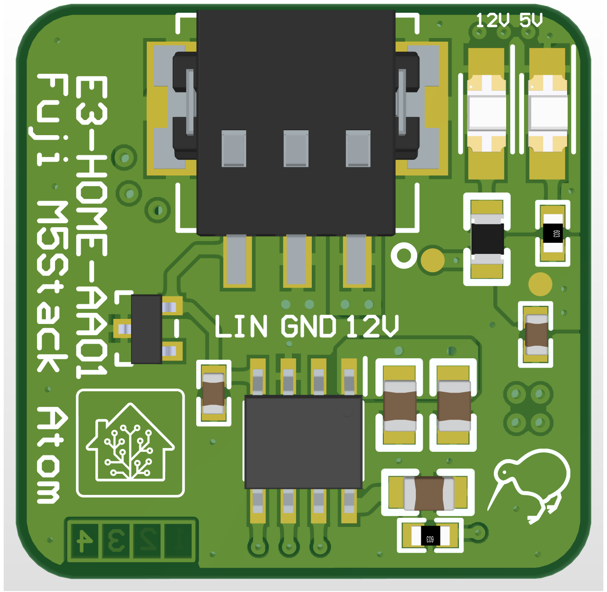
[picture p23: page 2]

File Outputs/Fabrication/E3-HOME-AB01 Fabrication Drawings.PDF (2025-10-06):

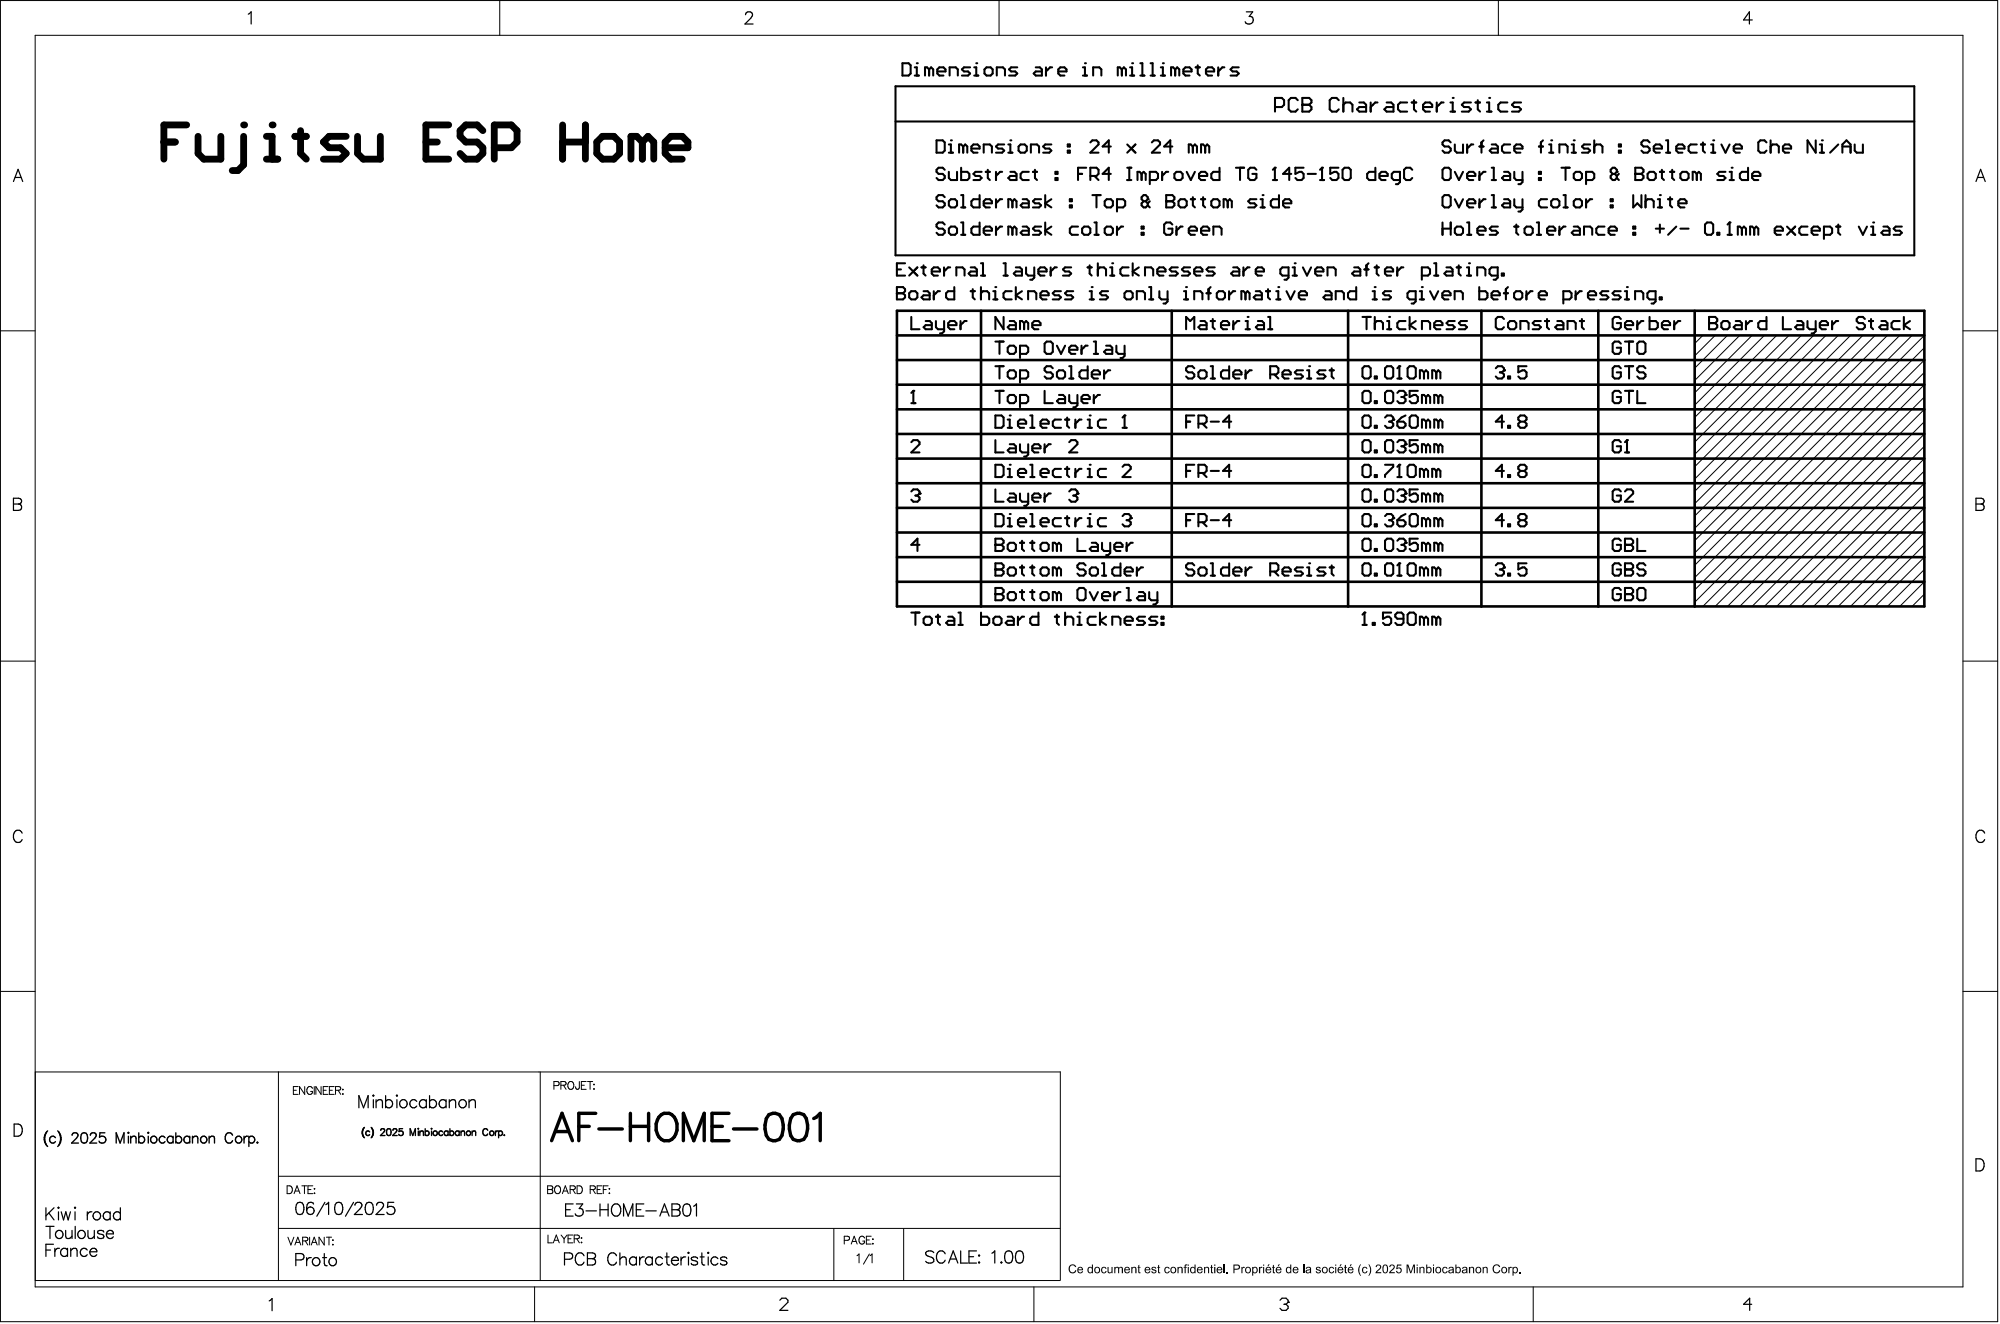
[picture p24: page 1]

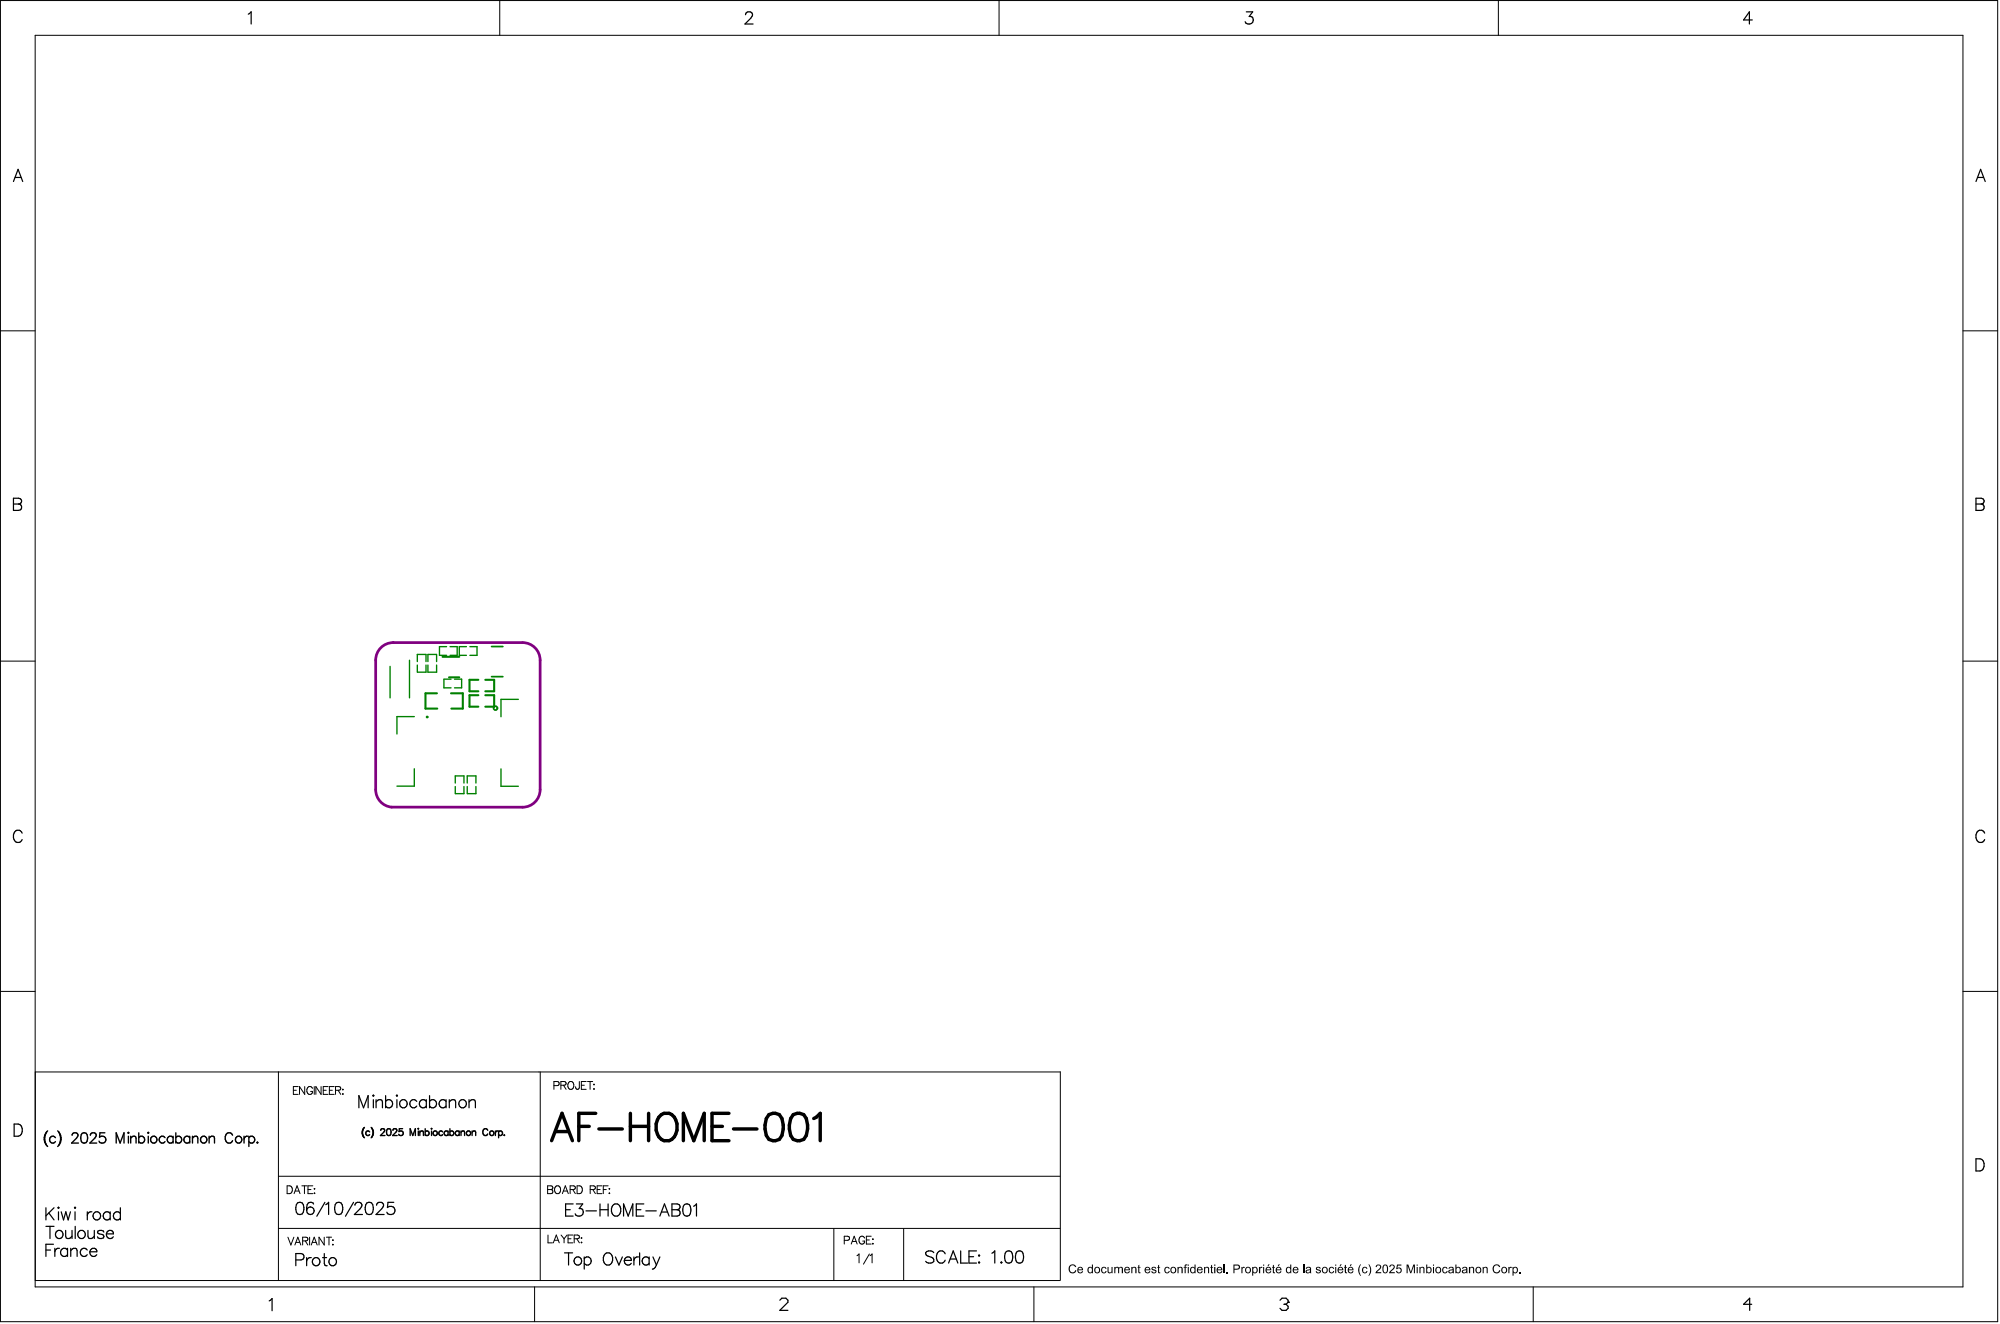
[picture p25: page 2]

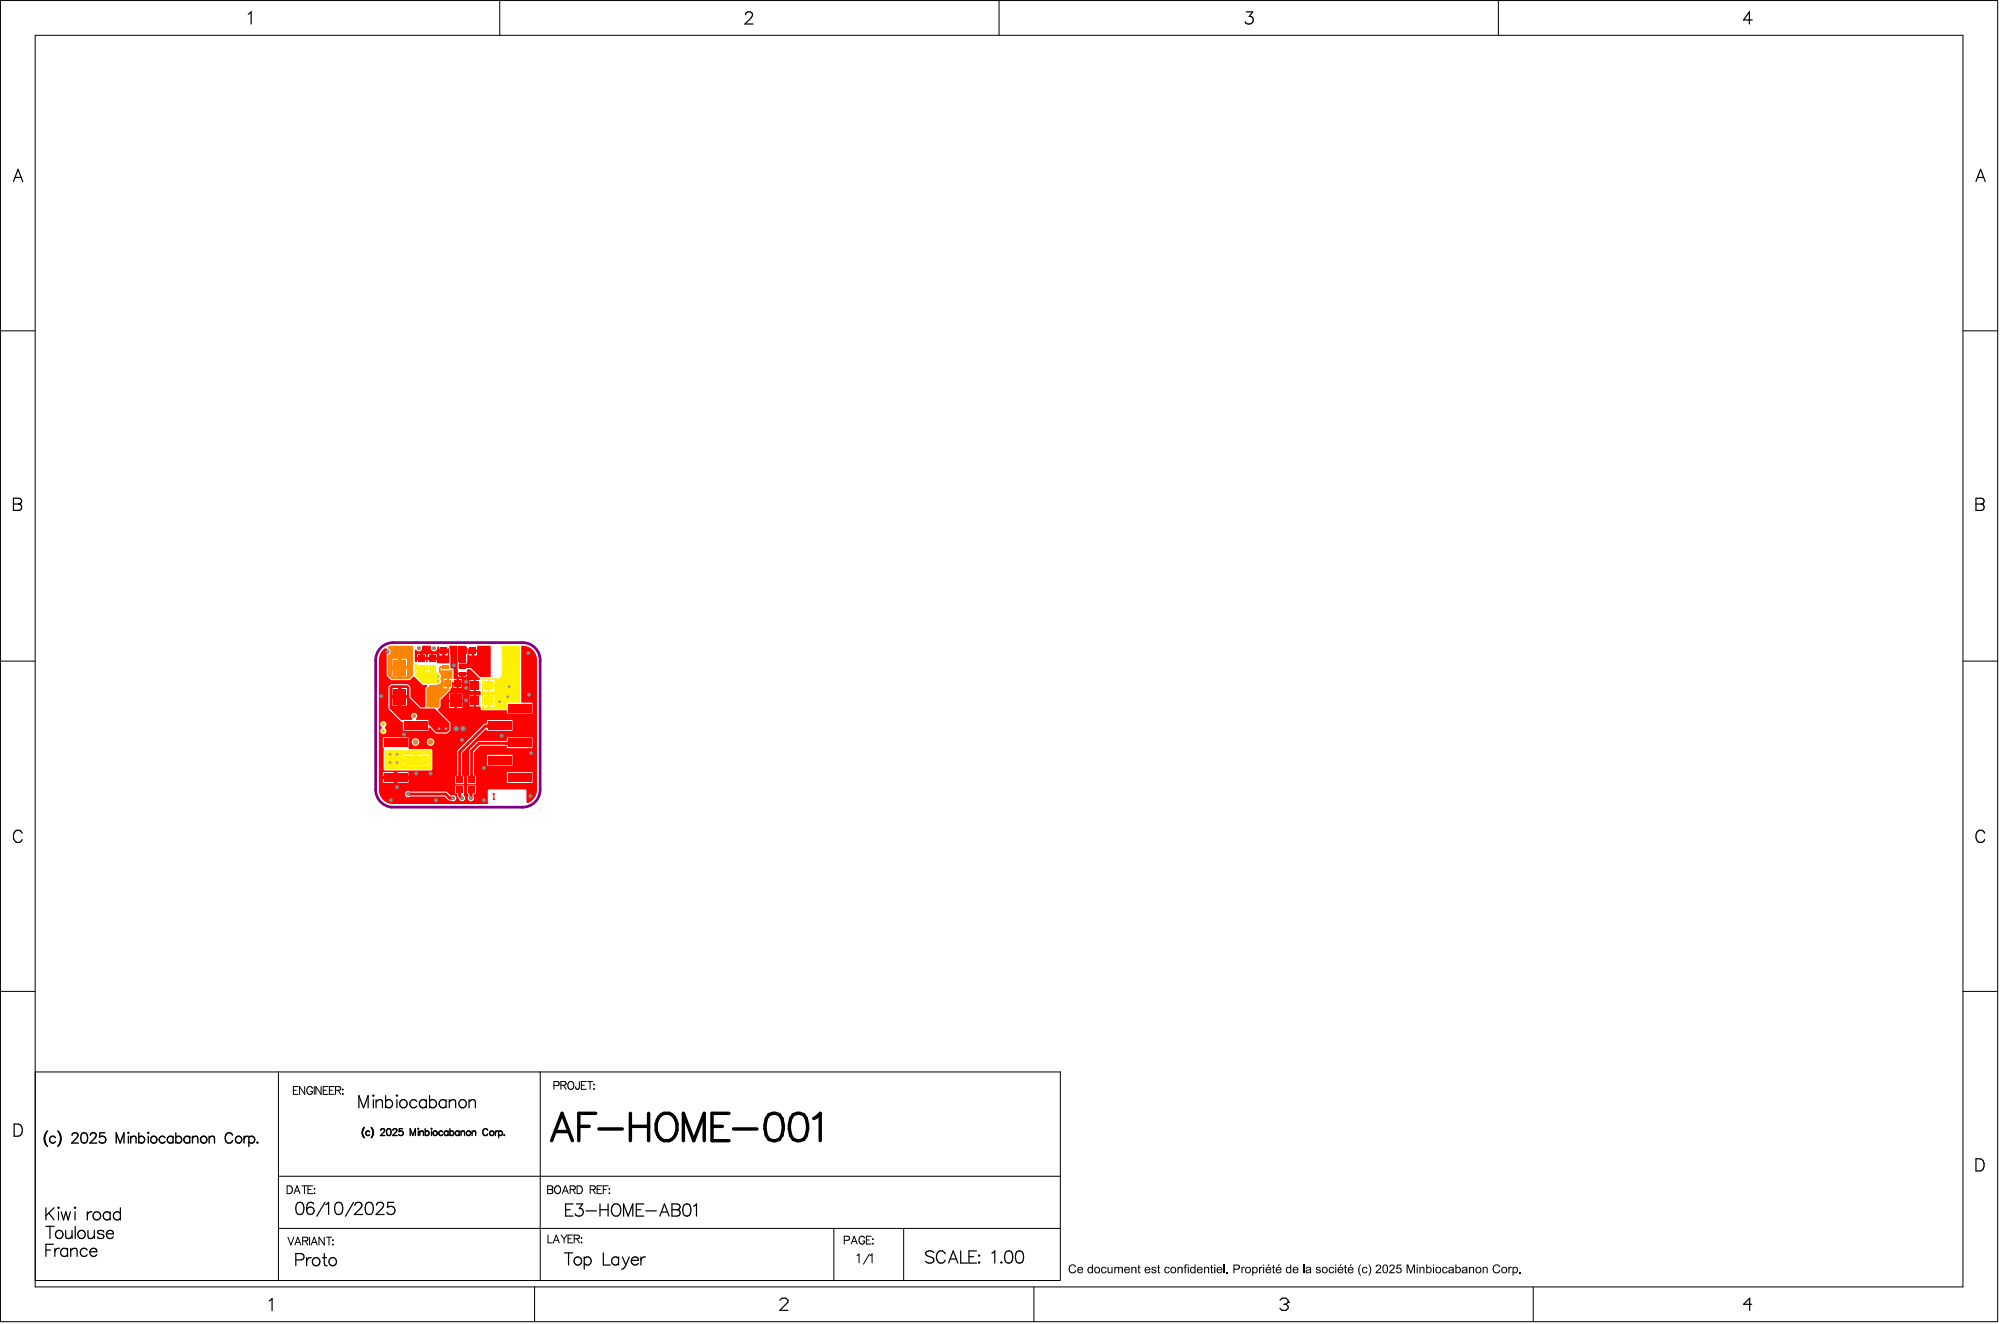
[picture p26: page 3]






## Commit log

2025-09-20 Add Altium project files
    [Cover Page.SchDoc, DCDC_LIN_CONN.SchDoc, Fujitsu_ESPHome.PcbDoc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]
2025-09-21 Update E3-HOME-AA01_Proto BOM.xlsx and Fujitsu_ESPHome.PcbDoc
    [E3-HOME-AA01_Proto BOM.xlsx, Fujitsu_ESPHome.PcbDoc]
2025-09-21 Generate all output files
    [E3-HOME-AA01_Proto BOM Odoo.csv, E3-HOME-AA01_Proto BOM.xlsx, E3-HOME-AA01_Proto DXF.DXF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]
2025-10-06 Fix issues : revert J101 and Led resistors values
    [DCDC_LIN_CONN.SchDoc, Fujitsu_ESPHome.PcbDoc, Fujitsu_ESPHome.PrjPCB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]
2025-10-06 Generate all output fils for AB01 version
    [E3-HOME-AA01_Proto BOM Odoo.csv, E3-HOME-AA01_Proto BOM.xlsx, E3-HOME-AA01_Proto DXF.DXF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]
